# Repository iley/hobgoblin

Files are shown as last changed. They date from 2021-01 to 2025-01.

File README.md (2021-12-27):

# Hobgoblin: Z80-based single-board computer

## Specs

 - Z80 CPU running at 10MHz
 - 64 KiB RAM
 - 8 x 16 KiB ROM. ROM bank is selectable with a DIP switch
 - ROM can be paged out for CP/M compatibility
 - Built-in usb-to-serial adapter for convenience of use with modern computers
 - 2 RC2014-compatible extension slots.

## Memory map

```
 FFFF ┌─────────┐
      │         │
      │         │
      │         │
      │         │
      │   RAM   │
      │         │
      │         │
      │         │
 4000 ├─────────┤
      │         │
      │   ROM   │
      │         │
 0000 └─────────┘
```

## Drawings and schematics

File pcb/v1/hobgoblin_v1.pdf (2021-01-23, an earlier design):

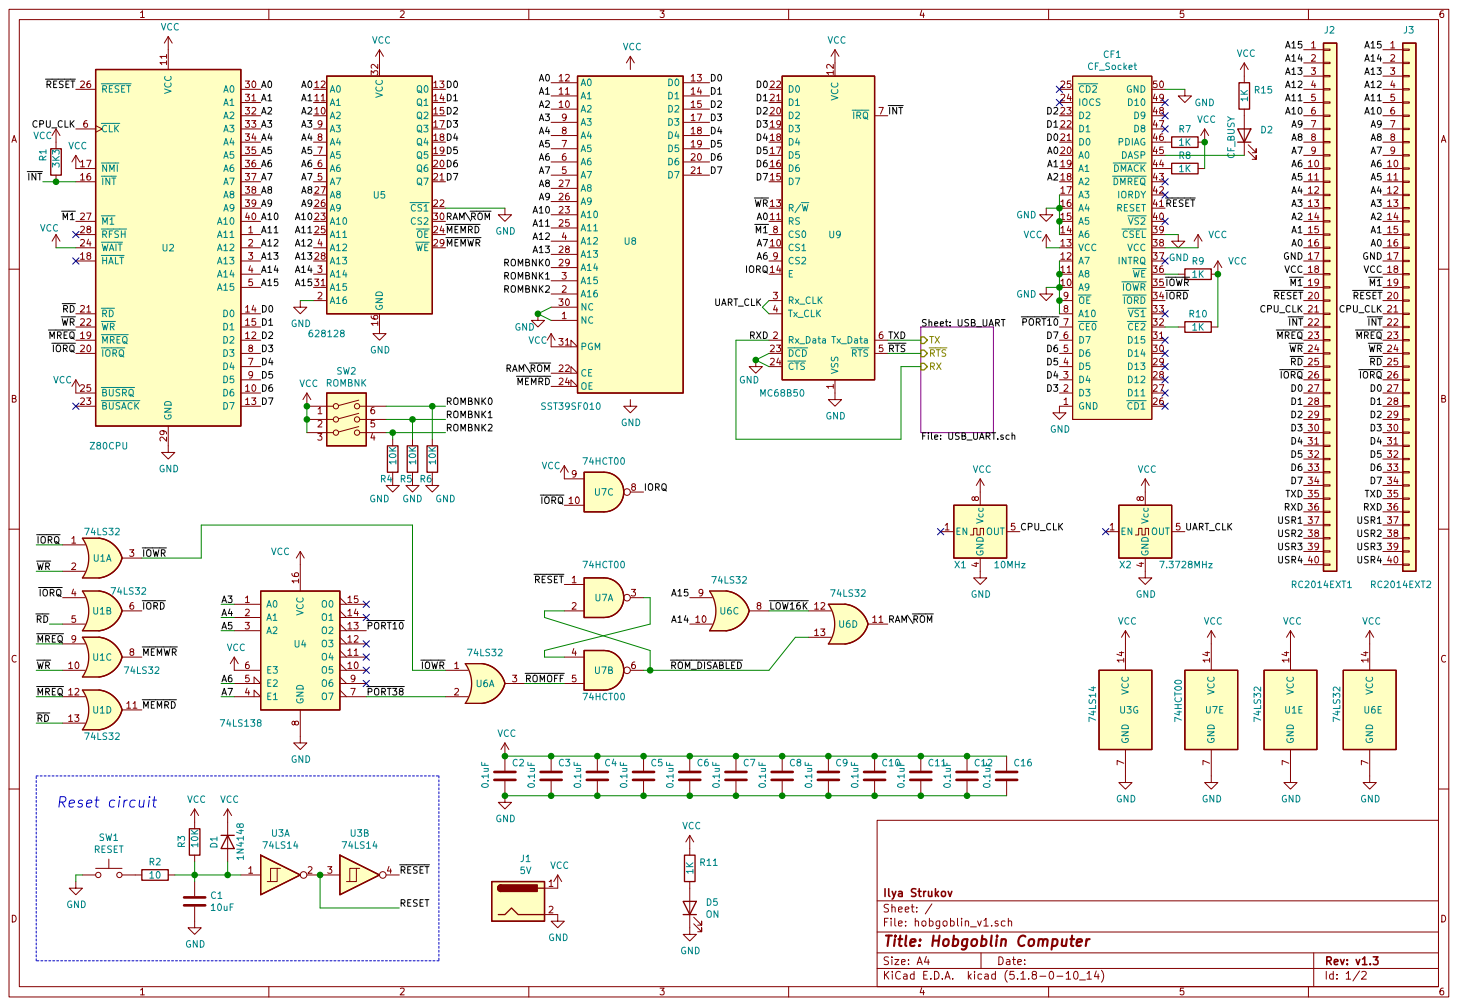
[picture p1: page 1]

4 OUT 5 Vcc 8 X2 7.3728MHz GND D1 1N4148 VCC
VCCGND

4 OUT 5 Vcc 8 X1 10MHz EN 1 GND

Ilya Strukov
File: hobgoblin_v1.sch Sheet: /
Id: 1/2 Title: Hobgoblin Computer

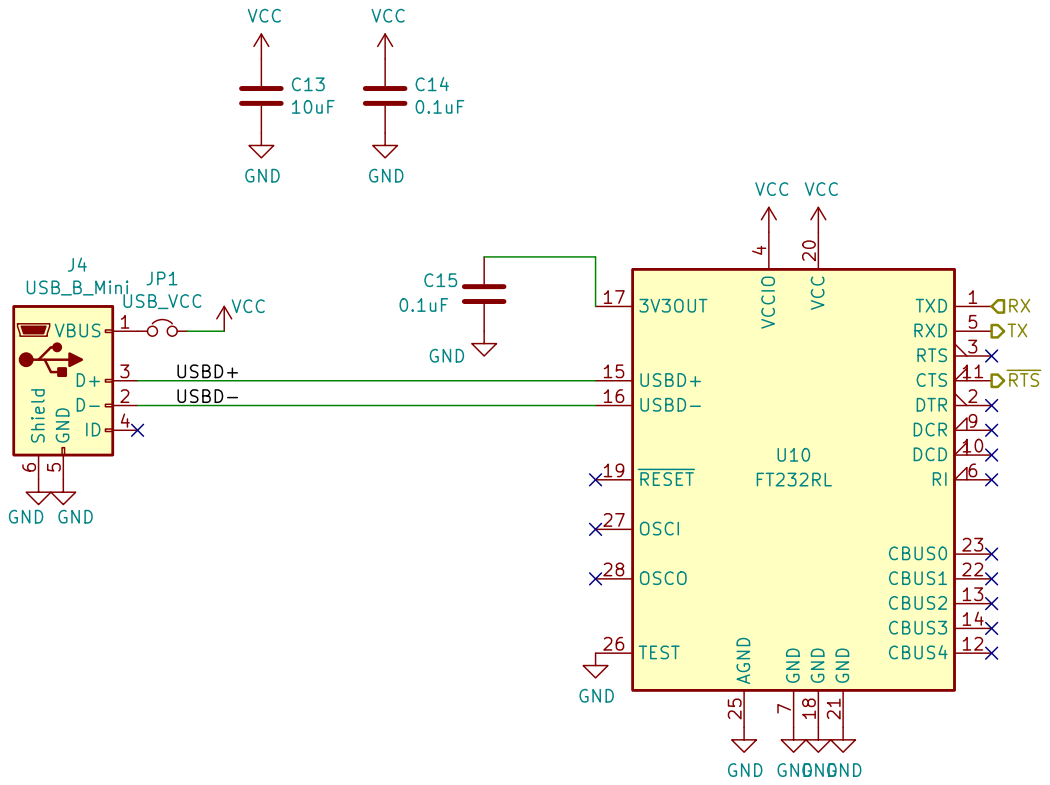
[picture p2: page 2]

10uF VCC GND
VCC VCC GND GNDGNDGND GND

Ilya Strukov
Sheet: /USB_UART/
File: USB_UART.sch
Id: 2/2 Title: Hobgoblin Computer

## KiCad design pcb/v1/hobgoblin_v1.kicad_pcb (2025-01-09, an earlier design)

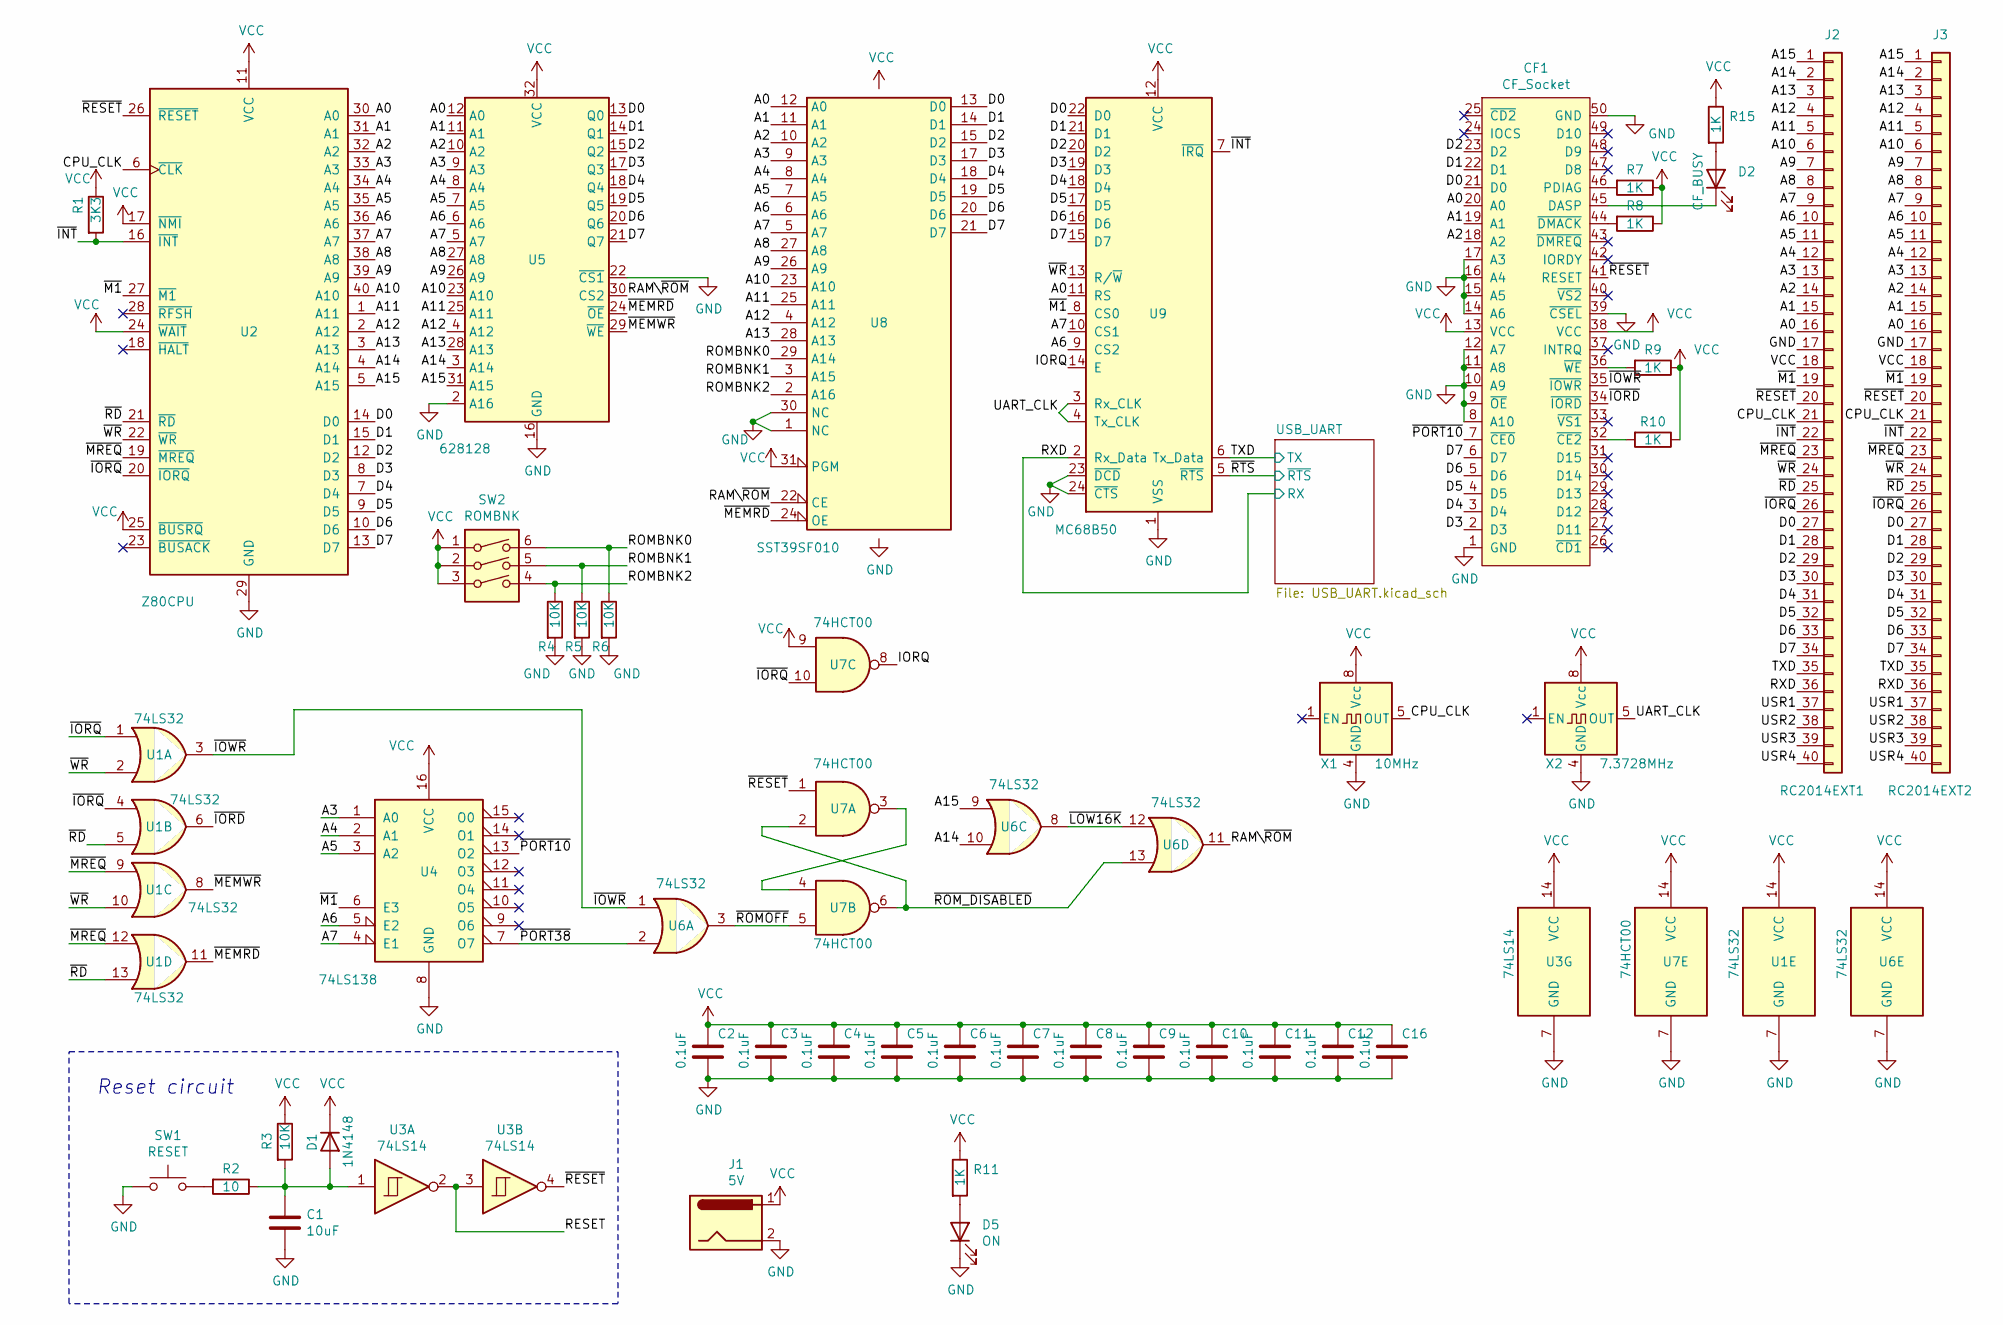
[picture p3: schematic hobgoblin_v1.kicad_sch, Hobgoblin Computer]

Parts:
C1: 10uF; CP_Radial_D4.0mm_P1.50mm
C2, C3, C4, C5, C6, C7, C8, C9, C10, C11, C12, C16: 0.1uF; C_Disc_D3.8mm_W2.6mm_P2.50mm
CF1: CF_Socket; CF-Card_3M_N7E507516PK20
D1: 1N4148; D_DO-35_SOD27_P7.62mm_Horizontal
D2: CF_BUSY; LED_D3.0mm
D5: ON; LED_D3.0mm
J1: 5V; BarrelJack_Horizontal
J2: RC2014EXT1; RC2014_Connector
J3: RC2014EXT2; RC2014_Connector
R1: 3K3; R_Axial_DIN0207_L6.3mm_D2.5mm_P10.16mm_Horizontal
R2: 10; R_Axial_DIN0207_L6.3mm_D2.5mm_P10.16mm_Horizontal
R3, R4, R5, R6: 10K; R_Axial_DIN0207_L6.3mm_D2.5mm_P10.16mm_Horizontal
R7, R8, R9, R10, R11, R15: 1K; R_Axial_DIN0207_L6.3mm_D2.5mm_P10.16mm_Horizontal
SW1: RESET; SW_PUSH_6mm
SW2: ROMBNK; SW_DIP_SPSTx03_Slide_6.7x9.18mm_W7.62mm_P2.54mm_LowProfile
U1, U6: 74LS32; DIP-14_W7.62mm_LongPads
U2: Z80CPU; DIP-40_W15.24mm_LongPads
U3: 74LS14; DIP-14_W7.62mm_LongPads
U4: 74LS138; DIP-16_W7.62mm_LongPads
U5: 628128; DIP-32_W15.24mm_LongPads
U7: 74HCT00; DIP-14_W7.62mm_LongPads
U8: SST39SF010; DIP-32_W15.24mm_LongPads
U9: MC68B50; DIP-24_W15.24mm_LongPads
X1: 10MHz; Oscillator_DIP-8
X2: 7.3728MHz; Oscillator_DIP-8

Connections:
/A0: CF1.20 (A0), J2.16, J3.16, U2.30 (A0), U5.12 (A0), U8.12 (A0), U9.11 (RS)
/A1: CF1.19 (A1), J2.15, J3.15, U2.31 (A1), U5.11 (A1), U8.11 (A1)
/A2: CF1.18 (A2), J2.14, J3.14, U2.32 (A2), U5.10 (A2), U8.10 (A2)
/A3: J2.13, J3.13, U2.33 (A3), U4.1 (A0), U5.9 (A3), U8.9 (A3)
/A4: J2.12, J3.12, U2.34 (A4), U4.2 (A1), U5.8 (A4), U8.8 (A4)
/A5: J2.11, J3.11, U2.35 (A5), U4.3 (A2), U5.7 (A5), U8.7 (A5)
/A6: J2.10, J3.10, U2.36 (A6), U4.5 (E2), U5.6 (A6), U8.6 (A6), U9.9 (CS2)
/A7: J2.9, J3.9, U2.37 (A7), U4.4 (E1), U5.5 (A7), U8.5 (A7), U9.10 (CS1)
/A8: J2.8, J3.8, U2.38 (A8), U5.27 (A8), U8.27 (A8)
/A9: J2.7, J3.7, U2.39 (A9), U5.26 (A9), U8.26 (A9)
/A10: J2.6, J3.6, U2.40 (A10), U5.23 (A10), U8.23 (A10)
/A11: J2.5, J3.5, U2.1 (A11), U5.25 (A11), U8.25 (A11)
/A12: J2.4, J3.4, U2.2 (A12), U5.4 (A12), U8.4 (A12)
/A13: J2.3, J3.3, U2.3 (A13), U5.28 (A13), U8.28 (A13)
/A14: J2.2, J3.2, U2.4 (A14), U5.3 (A14), U6.10
/A15: J2.1, J3.1, U2.5 (A15), U5.31 (A15), U6.9
/CPU_CLK: J2.21, J3.21, U2.6 (~CLK), X1.5 (OUT)
/D0: CF1.21 (D0), J2.27, J3.27, U2.14 (D0), U5.13 (Q0), U8.13 (D0), U9.22 (D0)
/D1: CF1.22 (D1), J2.28, J3.28, U2.15 (D1), U5.14 (Q1), U8.14 (D1), U9.21 (D1)
/D2: CF1.23 (D2), J2.29, J3.29, U2.12 (D2), U5.15 (Q2), U8.15 (D2), U9.20 (D2)
/D3: CF1.2 (D3), J2.30, J3.30, U2.8 (D3), U5.17 (Q3), U8.17 (D3), U9.19 (D3)
/D4: CF1.3 (D4), J2.31, J3.31, U2.7 (D4), U5.18 (Q4), U8.18 (D4), U9.18 (D4)
/D5: CF1.4 (D5), J2.32, J3.32, U2.9 (D5), U5.19 (Q5), U8.19 (D5), U9.17 (D5)
/D6: CF1.5 (D6), J2.33, J3.33, U2.10 (D6), U5.20 (Q6), U8.20 (D6), U9.16 (D6)
/D7: CF1.6 (D7), J2.34, J3.34, U2.13 (D7), U5.21 (Q7), U8.21 (D7), U9.15 (D7)
/IORQ: U7.8, U9.14 (E)
/RAM\~ROM: U5.30 (CS2), U6.11, U8.22 (CE)
/RESET: U3.2, U3.3
/ROMBNK0: R6.1, SW2.6, U8.29 (A14)
/ROMBNK1: R5.1, SW2.5, U8.3 (A15)
/ROMBNK2: R4.1, SW2.4, U8.2 (A16)
/RXD: J2.36, J3.36, U9.2 (Rx_Data); also elsewhere on the board
/TXD: J2.35, J3.35, U9.6 (Tx_Data); also elsewhere on the board
/UART_CLK: U9.3 (Rx_CLK), U9.4 (Tx_CLK), X2.5 (OUT)
/USR1: J2.37, J3.37
/USR2: J2.38, J3.38
/USR3: J2.39, J3.39
/USR4: J2.40, J3.40
/~INT: J2.22, J3.22, R1.2, U2.16 (~INT), U9.7 (~IRQ)
/~IORD: CF1.34 (~IORD), U1.6
/~IORQ: J2.26, J3.26, U1.1, U1.4, U2.20 (~IORQ), U7.10
/~IOWR: CF1.35 (~IOWR), U1.3, U6.1
/~LOW16K: U6.8, U6.12
/~M1: J2.19, J3.19, U2.27 (~M1), U4.6 (E3), U9.8 (CS0)
/~MEMRD: U1.11, U5.24 (~OE), U8.24 (OE)
/~MEMWR: U1.8, U5.29 (~WE)
/~MREQ: J2.23, J3.23, U1.9, U1.12, U2.19 (~MREQ)
/~PORT10: CF1.7 (~CE0), U4.13 (O2)
/~PORT38: U4.7 (O7), U6.2
/~RD: J2.25, J3.25, U1.5, U1.13, U2.21 (~RD)
/~RESET: CF1.41 (RESET), J2.20, J3.20, U2.26 (~RESET), U3.4, U7.1
/~ROMOFF: U6.3, U7.5
/~ROM_DISABLED: U6.13, U7.2, U7.6
/~RTS: U9.5 (~RTS); also elsewhere on the board
/~WR: J2.24, J3.24, U1.2, U1.10, U2.22 (~WR), U9.13 (R/~W)
GND: C1.2, C2.2, C3.2, C4.2, C5.2, C6.2, C7.2, C8.2, C9.2, C10.2, C11.2, C12.2, C16.2, CF1.1 (GND), CF1.8 (A10), CF1.9 (~OE), CF1.10 (A9), CF1.11 (A8), CF1.12 (A7), CF1.14 (A6), CF1.15 (A5), CF1.16 (A4), CF1.17 (A3), CF1.39 (~CSEL), CF1.50 (GND), D5.1 (K), J1.2, J2.17, J3.17, R4.2, R5.2, R6.2, SW1.1, U1.7 (GND), U2.29 (GND), U3.7 (GND), U4.8 (GND), U5.2 (A16), U5.16 (GND), U5.22 (~CS1), U6.7 (GND), U7.7 (GND), U8.1 (NC), U8.16 (GND), U8.30 (NC), U9.1 (VSS), U9.23 (~DCD), U9.24 (~CTS), X1.4 (GND), X2.4 (GND); also elsewhere on the board
unnamed: C1.1, D1.2 (A), R2.1, R3.2, U3.1
unnamed: CF1.32 (~CE2), R10.2
unnamed: CF1.36 (~WE), R9.2
unnamed: CF1.44 (~DMACK), R8.2
unnamed: CF1.45 (DASP), D2.1 (K)
unnamed: CF1.46 (PDIAG), R7.2
unnamed: D2.2 (A), R15.2
unnamed: D5.2 (A), R11.2
unnamed: R2.2, SW1.2
unnamed: U7.3, U7.4
VCC: C2.1, C3.1, C4.1, C5.1, C6.1, C7.1, C8.1, C9.1, C10.1, C11.1, C12.1, C16.1, CF1.13 (VCC), CF1.38 (VCC), D1.1 (K), J1.1, J2.18, J3.18, R1.1, R3.1, R7.1, R8.1, R9.1, R10.1, R11.1, R15.1, SW2.1, SW2.2, SW2.3, U1.14 (VCC), U2.11 (VCC), U2.17 (~NMI), U2.24 (~WAIT), U2.25 (~BUSRQ), U3.14 (VCC), U4.16 (VCC), U5.32 (VCC), U6.14 (VCC), U7.9, U7.14 (VCC), U8.31 (PGM), U8.32 (VCC), U9.12 (VCC), X1.8 (Vcc), X2.8 (Vcc); also elsewhere on the board

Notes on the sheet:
Reset circuit

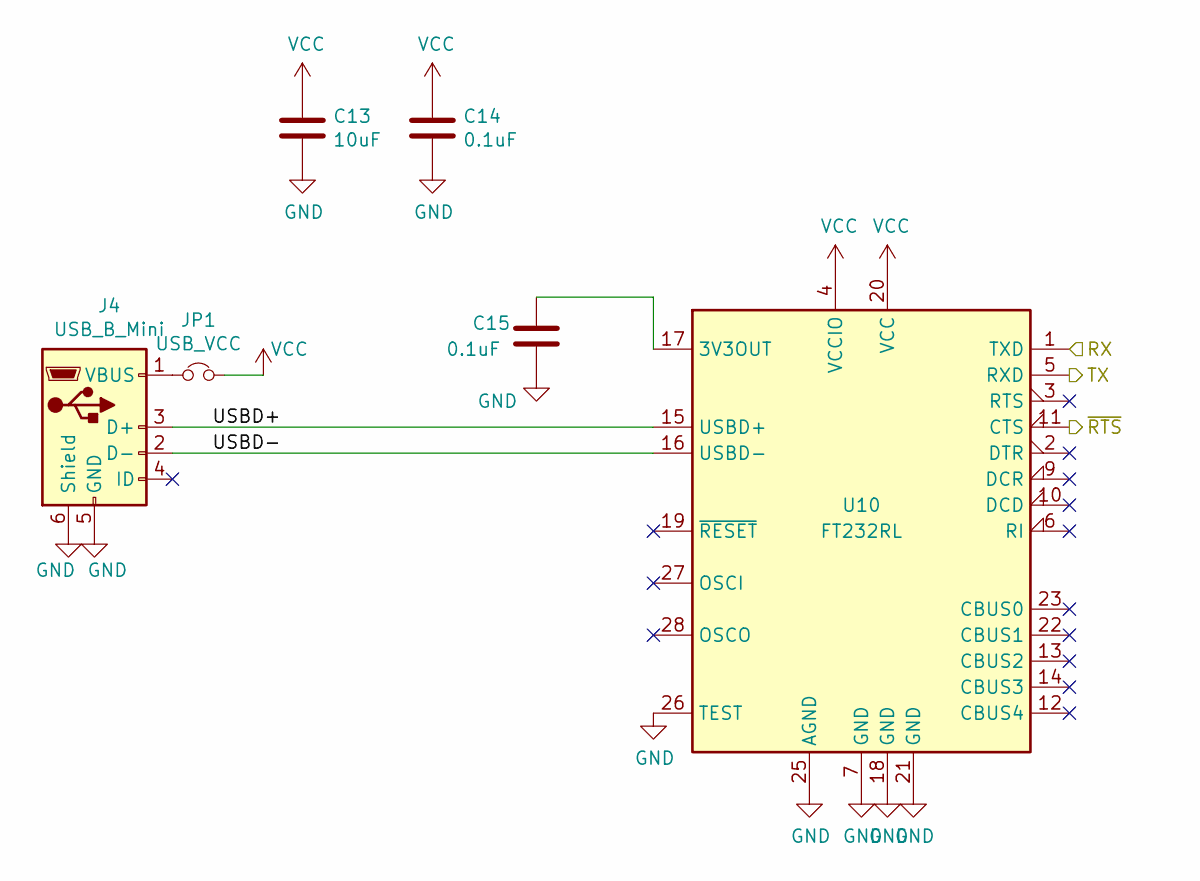
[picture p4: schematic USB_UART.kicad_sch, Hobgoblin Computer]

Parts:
C13: 10uF; CP_Radial_D4.0mm_P1.50mm
C14, C15: 0.1uF; C_Disc_D3.8mm_W2.6mm_P2.50mm
J4: USB_B_Mini; USB_Mini-B_Lumberg_2486_01_Horizontal
JP1: USB_VCC; PinHeader_1x02_P2.54mm_Vertical
U10: FT232RL; SSOP-28_5.3x10.2mm_P0.65mm

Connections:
/RXD: U10.1 (TXD); also elsewhere on the board
/TXD: U10.5 (RXD); also elsewhere on the board
/USB_UART/USBD+: J4.3 (D+), U10.15 (USBD+)
/USB_UART/USBD-: J4.2 (D-), U10.16 (USBD-)
/~RTS: U10.11 (CTS); also elsewhere on the board
GND: C13.2, C14.2, C15.1, J4.5 (GND), J4.6 (Shield), U10.7 (GND), U10.18 (GND), U10.21 (GND), U10.25 (AGND), U10.26 (TEST); also elsewhere on the board
unnamed: C15.2, U10.17 (3V3OUT)
unnamed: J4.1 (VBUS), JP1.1
VCC: C13.1, C14.1, JP1.2, U10.4 (VCCIO), U10.20 (VCC); also elsewhere on the board

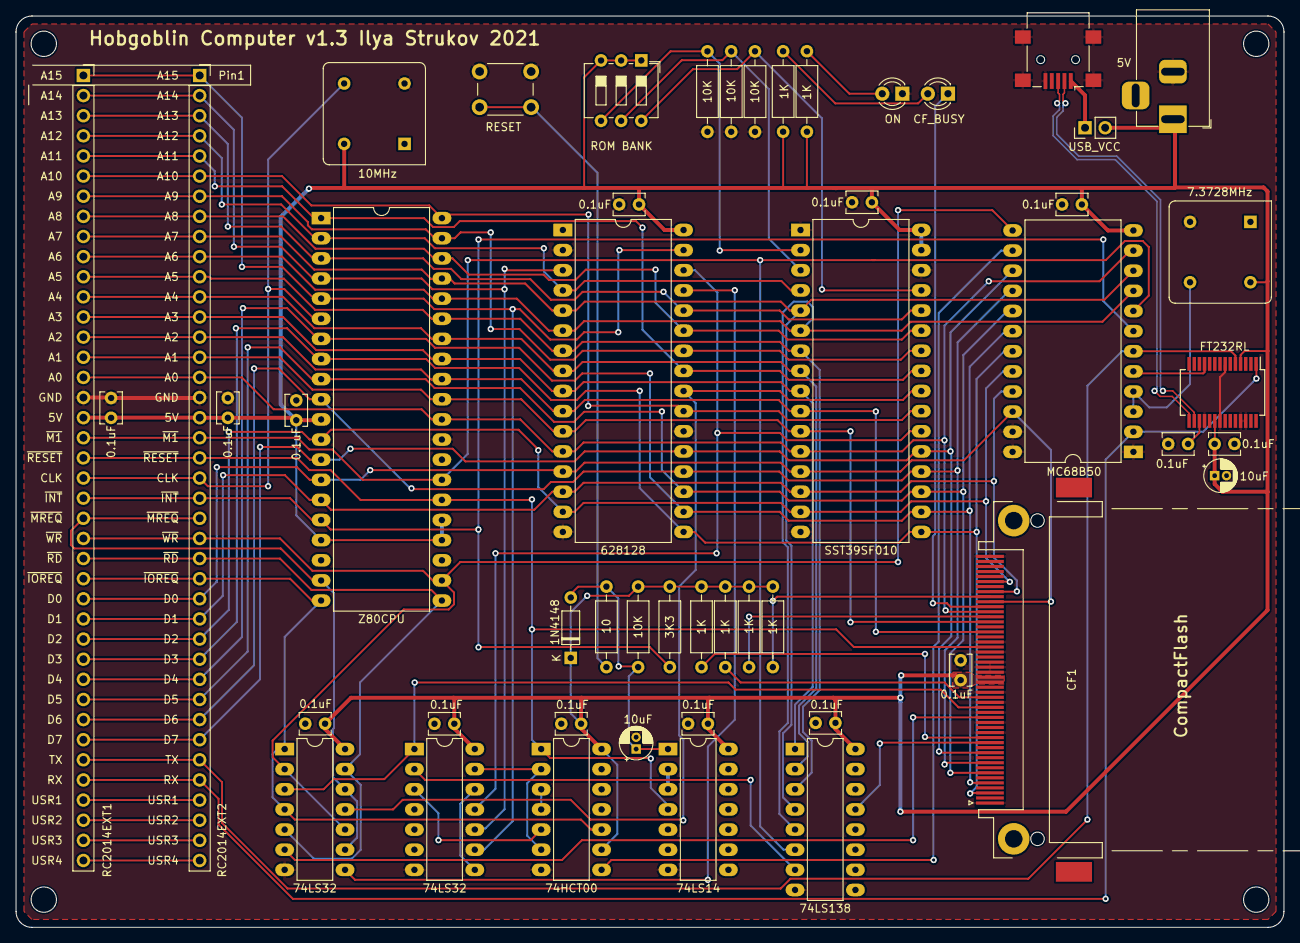
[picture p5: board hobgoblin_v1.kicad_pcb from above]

Board: 2 copper layers, 160.0 x 115.0 mm, 51 parts (0 on the bottom side), 71 nets.

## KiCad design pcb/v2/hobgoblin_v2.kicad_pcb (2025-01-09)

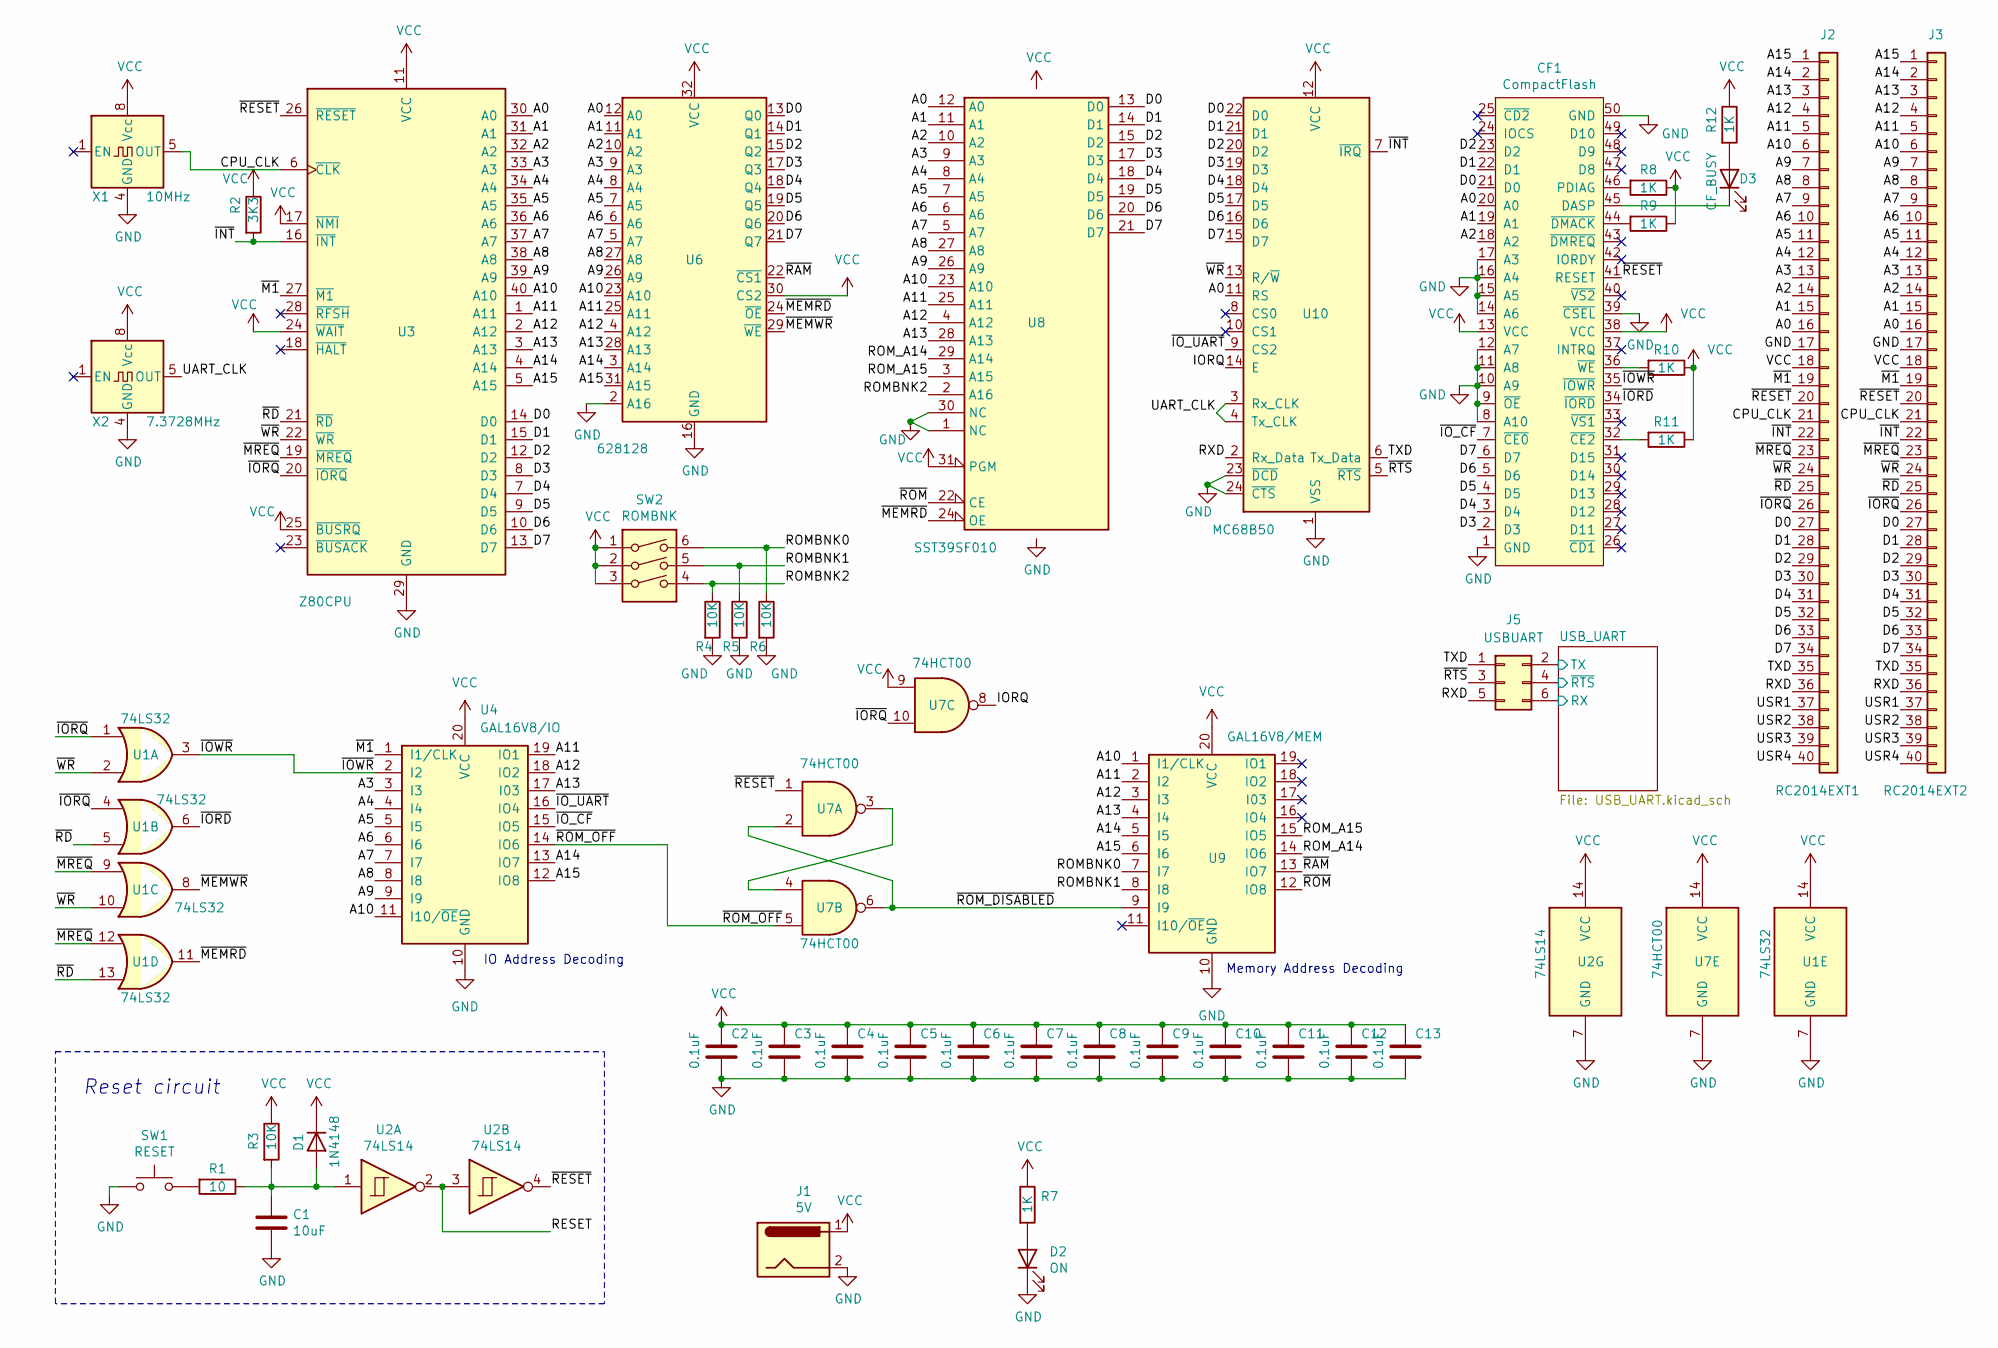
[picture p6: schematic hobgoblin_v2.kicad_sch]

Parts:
C1: 10uF; CP_Radial_D4.0mm_P1.50mm
C2, C3, C4, C5, C6, C7, C8, C9, C10, C11, C12, C13: 0.1uF; C_Disc_D3.8mm_W2.6mm_P2.50mm
CF1: CompactFlash; CF-Card_3M_N7E507516PK20
D1: 1N4148; D_DO-35_SOD27_P7.62mm_Horizontal
D2: ON; LED_D3.0mm
D3: CF_BUSY; LED_D3.0mm
J1: 5V; BarrelJack_Horizontal
J2: RC2014EXT1; RC2014_Connector
J3: RC2014EXT2; RC2014_Connector
J5: USBUART; PinHeader_2x03_P2.54mm_Vertical
R1: 10; R_Axial_DIN0207_L6.3mm_D2.5mm_P10.16mm_Horizontal
R2: 3K3; R_Axial_DIN0207_L6.3mm_D2.5mm_P10.16mm_Horizontal
R3, R4, R5, R6: 10K; R_Axial_DIN0207_L6.3mm_D2.5mm_P10.16mm_Horizontal
R7, R8, R9, R10, R11, R12: 1K; R_Axial_DIN0207_L6.3mm_D2.5mm_P10.16mm_Horizontal
SW1: RESET; SW_PUSH_6mm
SW2: ROMBNK; SW_DIP_SPSTx03_Slide_6.7x9.18mm_W7.62mm_P2.54mm_LowProfile
U1: 74LS32; DIP-14_W7.62mm_LongPads
U2: 74LS14; DIP-14_W7.62mm_LongPads
U3: Z80CPU; DIP-40_W15.24mm_Socket_LongPads
U4: GAL16V8/IO; DIP-20_W7.62mm_Socket_LongPads
U6: 628128; DIP-32_W15.24mm_LongPads
U7: 74HCT00; DIP-14_W7.62mm_LongPads
U8: SST39SF010; DIP-32_W15.24mm_Socket_LongPads
U9: GAL16V8/MEM; DIP-20_W7.62mm_Socket_LongPads
U10: MC68B50; DIP-24_W15.24mm_Socket_LongPads
X1: 10MHz; Oscillator_DIP-8
X2: 7.3728MHz; Oscillator_DIP-8

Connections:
/A0: CF1.20 (A0), J2.16, J3.16, U3.30 (A0), U6.12 (A0), U8.12 (A0), U10.11 (RS)
/A1: CF1.19 (A1), J2.15, J3.15, U3.31 (A1), U6.11 (A1), U8.11 (A1)
/A2: CF1.18 (A2), J2.14, J3.14, U3.32 (A2), U6.10 (A2), U8.10 (A2)
/A3: J2.13, J3.13, U3.33 (A3), U4.3 (I3), U6.9 (A3), U8.9 (A3)
/A4: J2.12, J3.12, U3.34 (A4), U4.4 (I4), U6.8 (A4), U8.8 (A4)
/A5: J2.11, J3.11, U3.35 (A5), U4.5 (I5), U6.7 (A5), U8.7 (A5)
/A6: J2.10, J3.10, U3.36 (A6), U4.6 (I6), U6.6 (A6), U8.6 (A6)
/A7: J2.9, J3.9, U3.37 (A7), U4.7 (I7), U6.5 (A7), U8.5 (A7)
/A8: J2.8, J3.8, U3.38 (A8), U4.8 (I8), U6.27 (A8), U8.27 (A8)
/A9: J2.7, J3.7, U3.39 (A9), U4.9 (I9), U6.26 (A9), U8.26 (A9)
/A10: J2.6, J3.6, U3.40 (A10), U4.11 (I10/~OE), U6.23 (A10), U8.23 (A10), U9.1 (I1/CLK)
/A11: J2.5, J3.5, U3.1 (A11), U4.19 (IO1), U6.25 (A11), U8.25 (A11), U9.2 (I2)
/A12: J2.4, J3.4, U3.2 (A12), U4.18 (IO2), U6.4 (A12), U8.4 (A12), U9.3 (I3)
/A13: J2.3, J3.3, U3.3 (A13), U4.17 (I03), U6.28 (A13), U8.28 (A13), U9.4 (I4)
/A14: J2.2, J3.2, U3.4 (A14), U4.13 (IO7), U6.3 (A14), U9.5 (I5)
/A15: J2.1, J3.1, U3.5 (A15), U4.12 (IO8), U6.31 (A15), U9.6 (I6)
/CPU_CLK: J2.21, J3.21, U3.6 (~CLK), X1.5 (OUT)
/D0: CF1.21 (D0), J2.27, J3.27, U3.14 (D0), U6.13 (Q0), U8.13 (D0), U10.22 (D0)
/D1: CF1.22 (D1), J2.28, J3.28, U3.15 (D1), U6.14 (Q1), U8.14 (D1), U10.21 (D1)
/D2: CF1.23 (D2), J2.29, J3.29, U3.12 (D2), U6.15 (Q2), U8.15 (D2), U10.20 (D2)
/D3: CF1.2 (D3), J2.30, J3.30, U3.8 (D3), U6.17 (Q3), U8.17 (D3), U10.19 (D3)
/D4: CF1.3 (D4), J2.31, J3.31, U3.7 (D4), U6.18 (Q4), U8.18 (D4), U10.18 (D4)
/D5: CF1.4 (D5), J2.32, J3.32, U3.9 (D5), U6.19 (Q5), U8.19 (D5), U10.17 (D5)
/D6: CF1.5 (D6), J2.33, J3.33, U3.10 (D6), U6.20 (Q6), U8.20 (D6), U10.16 (D6)
/D7: CF1.6 (D7), J2.34, J3.34, U3.13 (D7), U6.21 (Q7), U8.21 (D7), U10.15 (D7)
/IORQ: U7.8, U10.14 (E)
/RESET: U2.2, U2.3
/ROMBNK0: R6.1, SW2.6, U9.7 (I7)
/ROMBNK1: R5.1, SW2.5, U9.8 (I8)
/ROMBNK2: R4.1, SW2.4, U8.2 (A16)
/ROM_A14: U8.29 (A14), U9.14 (IO6)
/ROM_A15: U8.3 (A15), U9.15 (IO5)
/RXD: J2.36, J3.36, J5.5, U10.2 (Rx_Data)
/TXD: J2.35, J3.35, J5.1, U10.6 (Tx_Data)
/UART_CLK: U10.3 (Rx_CLK), U10.4 (Tx_CLK), X2.5 (OUT)
/USB_UART/RX: J5.6; also elsewhere on the board
/USB_UART/TX: J5.2; also elsewhere on the board
/USB_UART/~RTS: J5.4; also elsewhere on the board
/USR1: J2.37, J3.37
/USR2: J2.38, J3.38
/USR3: J2.39, J3.39
/USR4: J2.40, J3.40
/~INT: J2.22, J3.22, R2.2, U3.16 (~INT), U10.7 (~IRQ)
/~IORD: CF1.34 (~IORD), U1.6
/~IORQ: J2.26, J3.26, U1.1, U1.4, U3.20 (~IORQ), U7.10
/~IOWR: CF1.35 (~IOWR), U1.3, U4.2 (I2)
/~IO_CF: CF1.7 (~CE0), U4.15 (IO5)
/~IO_UART: U4.16 (IO4), U10.9 (CS2)
/~M1: J2.19, J3.19, U3.27 (~M1), U4.1 (I1/CLK)
/~MEMRD: U1.11, U6.24 (~OE), U8.24 (OE)
/~MEMWR: U1.8, U6.29 (~WE)
/~MREQ: J2.23, J3.23, U1.9, U1.12, U3.19 (~MREQ)
/~RAM: U6.22 (~CS1), U9.13 (IO7)
/~RD: J2.25, J3.25, U1.5, U1.13, U3.21 (~RD)
/~RESET: CF1.41 (RESET), J2.20, J3.20, U2.4, U3.26 (~RESET), U7.1
/~ROM_DISABLED: U7.2, U7.6, U9.9 (I9)
/~ROM_OFF: U4.14 (IO6), U7.5
/~ROM: U8.22 (CE), U9.12 (IO8)
/~RTS: J5.3, U10.5 (~RTS)
/~WR: J2.24, J3.24, U1.2, U1.10, U3.22 (~WR), U10.13 (R/~W)
GND: C1.2, C2.2, C3.2, C4.2, C5.2, C6.2, C7.2, C8.2, C9.2, C10.2, C11.2, C12.2, C13.2, CF1.1 (GND), CF1.8 (A10), CF1.9 (~OE), CF1.10 (A9), CF1.11 (A8), CF1.12 (A7), CF1.14 (A6), CF1.15 (A5), CF1.16 (A4), CF1.17 (A3), CF1.39 (~CSEL), CF1.50 (GND), D2.1 (K), J1.2, J2.17, J3.17, R4.2, R5.2, R6.2, SW1.1, U1.7 (GND), U2.7 (GND), U3.29 (GND), U4.10 (GND), U6.2 (A16), U6.16 (GND), U7.7 (GND), U8.1 (NC), U8.16 (GND), U8.30 (NC), U9.10 (GND), U10.1 (VSS), U10.23 (~DCD), U10.24 (~CTS), X1.4 (GND), X2.4 (GND); also elsewhere on the board
unnamed: C1.1, D1.2 (A), R1.1, R3.2, U2.1
unnamed: CF1.32 (~CE2), R11.2
unnamed: CF1.36 (~WE), R10.2
unnamed: CF1.44 (~DMACK), R9.2
unnamed: CF1.45 (DASP), D3.1 (K)
unnamed: CF1.46 (PDIAG), R8.2
unnamed: D2.2 (A), R7.2
unnamed: D3.2 (A), R12.2
unnamed: R1.2, SW1.2
unnamed: U7.3, U7.4
VCC: C2.1, C3.1, C4.1, C5.1, C6.1, C7.1, C8.1, C9.1, C10.1, C11.1, C12.1, C13.1, CF1.13 (VCC), CF1.38 (VCC), D1.1 (K), J1.1, J2.18, J3.18, R2.1, R3.1, R7.1, R8.1, R9.1, R10.1, R11.1, R12.1, SW2.1, SW2.2, SW2.3, U1.14 (VCC), U2.14 (VCC), U3.11 (VCC), U3.17 (~NMI), U3.24 (~WAIT), U3.25 (~BUSRQ), U4.20 (VCC), U6.30 (CS2), U6.32 (VCC), U7.9, U7.14 (VCC), U8.31 (PGM), U8.32 (VCC), U9.20 (VCC), U10.12 (VCC), X1.8 (Vcc), X2.8 (Vcc); also elsewhere on the board

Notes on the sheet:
Reset circuit
IO Address Decoding
Memory Address Decoding

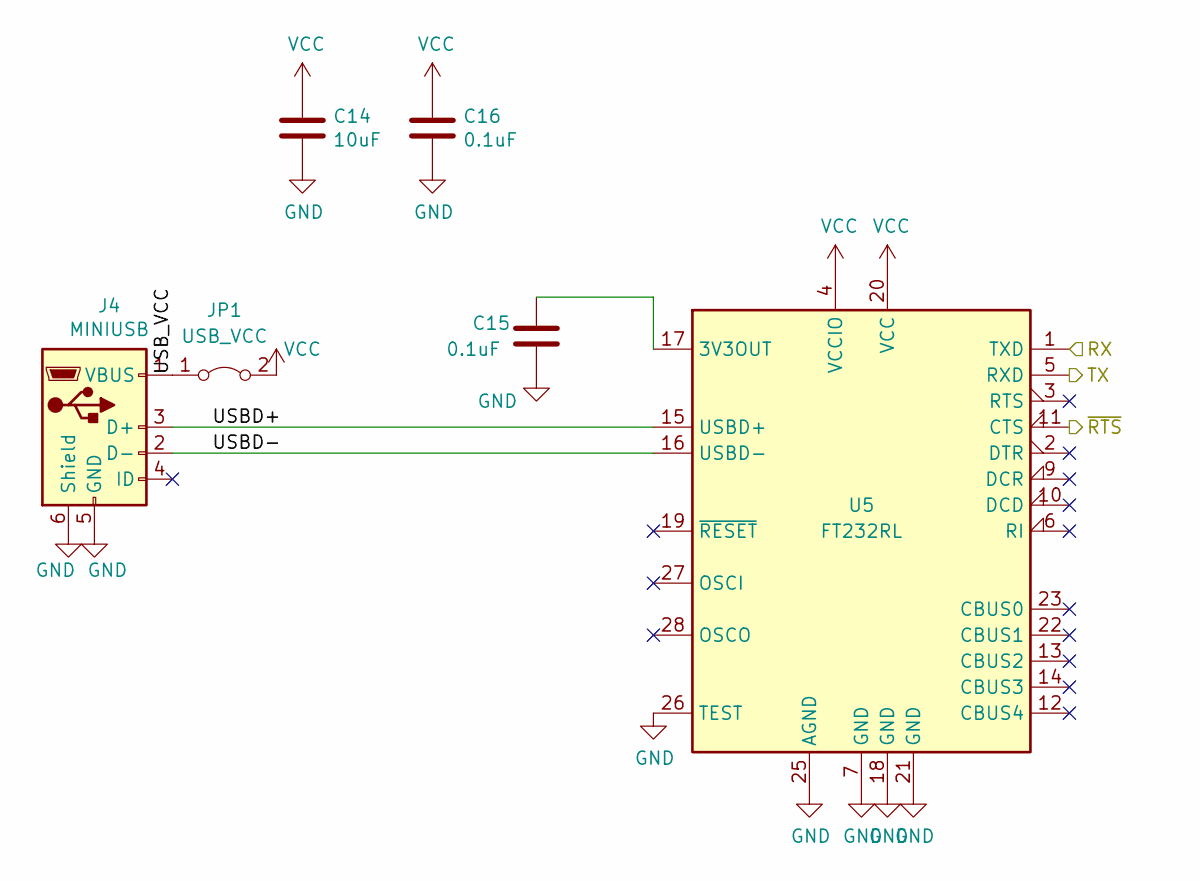
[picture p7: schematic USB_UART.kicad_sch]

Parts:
C14: 10uF; CP_Radial_D4.0mm_P1.50mm
C15, C16: 0.1uF; C_Disc_D3.8mm_W2.6mm_P2.50mm
J4: MINIUSB; USB_Mini-B_Lumberg_2486_01_Horizontal
JP1: USB_VCC; PinSocket_1x02_P2.54mm_Vertical
U5: FT232RL; SSOP-28_5.3x10.2mm_P0.65mm

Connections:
/USB_UART/RX: U5.1 (TXD); also elsewhere on the board
/USB_UART/TX: U5.5 (RXD); also elsewhere on the board
/USB_UART/USBD+: J4.3 (D+), U5.15 (USBD+)
/USB_UART/USBD-: J4.2 (D-), U5.16 (USBD-)
/USB_UART/USB_VCC: J4.1 (VBUS), JP1.1 (A)
/USB_UART/~RTS: U5.11 (CTS); also elsewhere on the board
GND: C14.2, C15.1, C16.2, J4.5 (GND), J4.6 (Shield), U5.7 (GND), U5.18 (GND), U5.21 (GND), U5.25 (AGND), U5.26 (TEST); also elsewhere on the board
unnamed: C15.2, U5.17 (3V3OUT)
VCC: C14.1, C16.1, JP1.2 (B), U5.4 (VCCIO), U5.20 (VCC); also elsewhere on the board

Board: 2 copper layers, 56 parts (0 on the bottom side), 76 nets, no tracks yet.

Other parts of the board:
H1: hole1; MountingHole_3.2mm_M3
H2: hole2; MountingHole_3.2mm_M3
H3: hole3; MountingHole_3.2mm_M3
H4: hole4; MountingHole_3.2mm_M3

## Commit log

2020-10-25 progress with the schematic
    [UART.sch, USB_UART.sch, hobgoblin_v1.kicad_pcb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]
2020-11-03 Finish the schematic
    [USB_UART.sch, hobgoblin_v1.kicad_pcb, hobgoblin_v1.sch]
2020-11-03 Place components on the PCB layout
    [USB_UART.sch, hobgoblin_v1.kicad_pcb, hobgoblin_v1.sch]
2020-11-05 Finish PCB layout
    [USB_UART.sch, hobgoblin_v1.kicad_pcb, hobgoblin_v1.sch]
2020-11-06 Add UART socket and other PCB improvements
    [USB_UART.sch, hobgoblin_v1.kicad_pcb, hobgoblin_v1.sch]
2020-11-06 Add CF busy LED
    [hobgoblin_v1.kicad_pcb]
2020-11-06 Flip the UART connector
    [hobgoblin_v1.kicad_pcb]
2020-11-06 PCB: final touches
    [hobgoblin_v1.kicad_pcb, hobgoblin_v1.sch]
2020-11-08 Minor PCB changes
    [hobgoblin_v1.kicad_pcb]
2020-12-24 Fix the CF card slot footprint (v1.1.)
    [hobgoblin_v1.kicad_pcb, hobgoblin_v1.sch]
2021-01-01 Fix CF footprint pin numbering
    [USB_UART.sch, hobgoblin_v1.kicad_pcb, hobgoblin_v1.sch]
2021-01-03 Reroute USB diff pair
    [hobgoblin_v1.kicad_pcb]
2021-01-03 Save the schematic as PDF
    [USB_UART.sch, hobgoblin_v1.sch]
2021-01-23 Fix IOWR/IORD pins on CF socket
    [hobgoblin_v1.kicad_pcb, hobgoblin_v1.sch]
2021-01-23 Clean up routing
    [USB_UART.sch, hobgoblin_v1.kicad_pcb]
2021-01-23 Update the schematic PDF
2021-01-24 Add missing traces
    [hobgoblin_v1.kicad_pcb]
2021-01-24 Final 1.3 routing improvements
    [hobgoblin_v1.kicad_pcb, hobgoblin_v1.sch]
2021-08-29 Implement a bus device, start CPU
2021-09-09 Switch to Bazel
2021-12-26 Convert PCB files to KiCAD v6
    [USB_UART.kicad_sch, hobgoblin_v1.kicad_pcb, hobgoblin_v1.kicad_sch]
2021-12-27 Rename CF Card connector footprint to match the actual part
    [hobgoblin_v1.kicad_pcb, hobgoblin_v1.kicad_sch]
2021-12-28 Start v2 schematic
    [USB_UART.kicad_sch, hobgoblin_v2.kicad_pcb, hobgoblin_v2.kicad_sch]
2021-12-29 Start using GALs in V2
    [hobgoblin_v2.kicad_pcb, hobgoblin_v2.kicad_sch]
2021-12-30 Draft component placement
    [USB_UART.kicad_sch, hobgoblin_v2.kicad_pcb, hobgoblin_v2.kicad_sch]
2021-12-30 Realign components
    [hobgoblin_v2.kicad_pcb]
2021-12-30 CF socket properties
    [hobgoblin_v2.kicad_pcb, hobgoblin_v2.kicad_sch]
2021-12-30 Tweak silkscreen
    [hobgoblin_v2.kicad_pcb]
2021-12-30 Add ground fills
    [hobgoblin_v2.kicad_pcb]
2021-12-31 In-progress PCB layout
    [USB_UART.kicad_sch, hobgoblin_v2.kicad_pcb]
2022-01-02 PCB layout in progress
    [hobgoblin_v2.kicad_pcb, hobgoblin_v2.kicad_sch]
2022-01-03 Made some progress in layout
    [hobgoblin_v2.kicad_pcb]
2025-01-09 Update to latest KiCAD version
    [USB_UART.kicad_sch, hobgoblin_v1.kicad_pcb, hobgoblin_v1.kicad_sch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]
